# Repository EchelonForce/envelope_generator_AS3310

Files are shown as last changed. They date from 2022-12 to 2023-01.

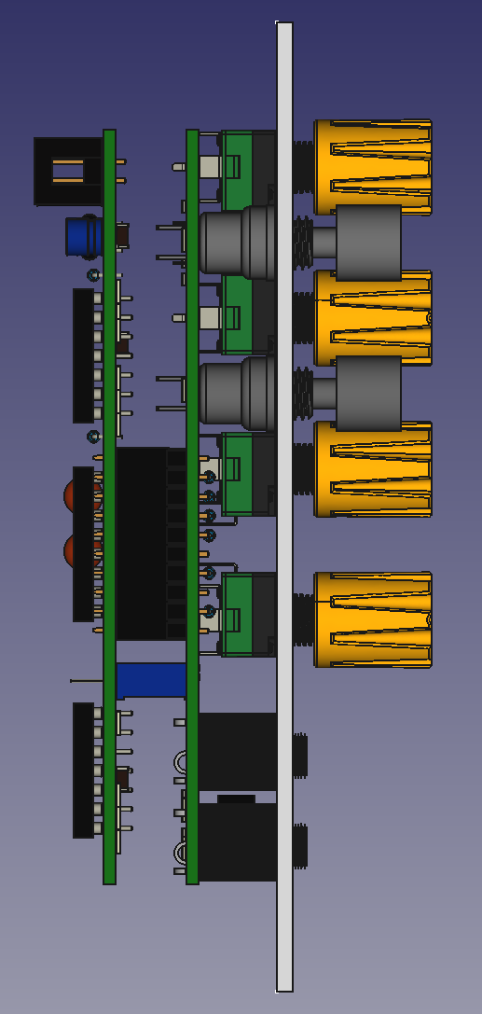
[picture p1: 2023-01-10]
front_panel_v1/render3.png

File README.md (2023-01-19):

# Eurorack Envelope Generator AS3310 

This is a design for a Eurorack Envelope Generator based on the AS3310.

Full write up: https://www.robotdialogs.com/2023/01/eurorack-envelope-generator-adsr-as3310.html

This work is licensed under a Creative Commons Attribution-NonCommercial-ShareAlike 4.0 International License. https://creativecommons.org/licenses/by-nc-sa/4.0/

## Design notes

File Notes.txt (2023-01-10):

Issues on v1:
 - Two header pins flipped (out/release) requires rework.

Changes for v1.1
 - Fix header pins flipped.
 - Add orientation of trim pots to silkscreen.

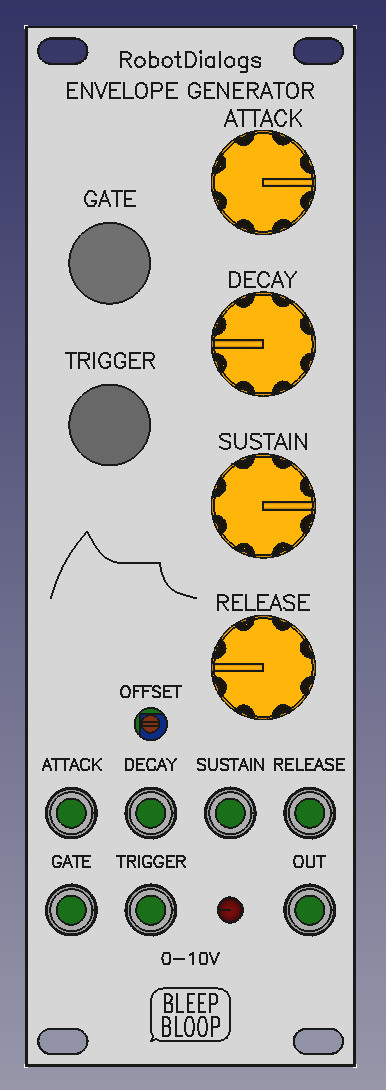
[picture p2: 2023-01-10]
front_panel_v1/render1.png

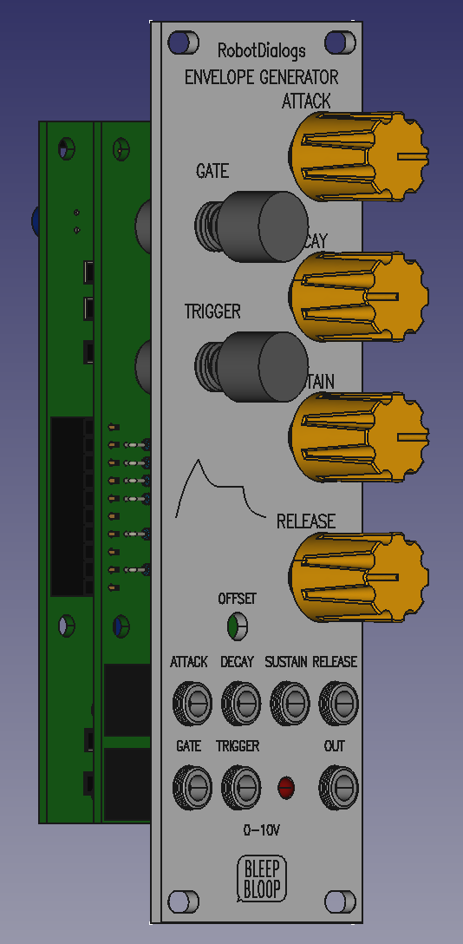
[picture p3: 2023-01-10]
front_panel_v1/render2.png

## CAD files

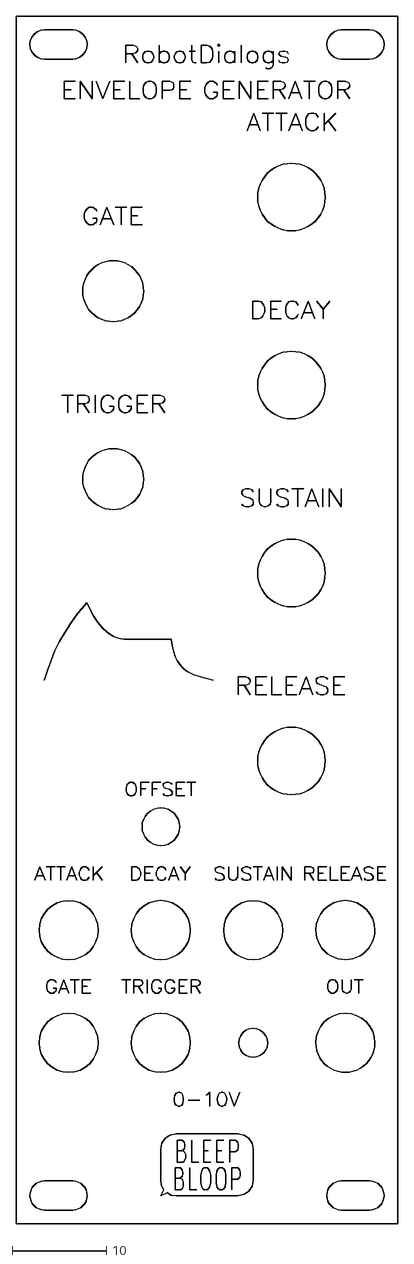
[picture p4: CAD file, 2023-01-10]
front_panel_v1/envelope_v1_front_panel_v1_engraving.dxf
40.5 x 128.4

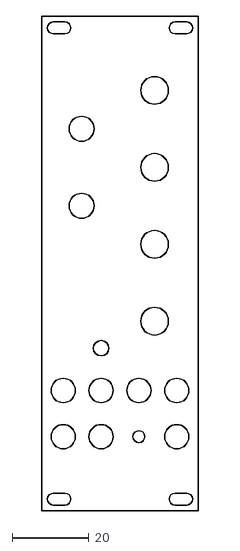
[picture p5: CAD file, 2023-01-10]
front_panel_v1/envelope_v1_front_panel_v1_no_engraving.dxf
40.6 x 128.5

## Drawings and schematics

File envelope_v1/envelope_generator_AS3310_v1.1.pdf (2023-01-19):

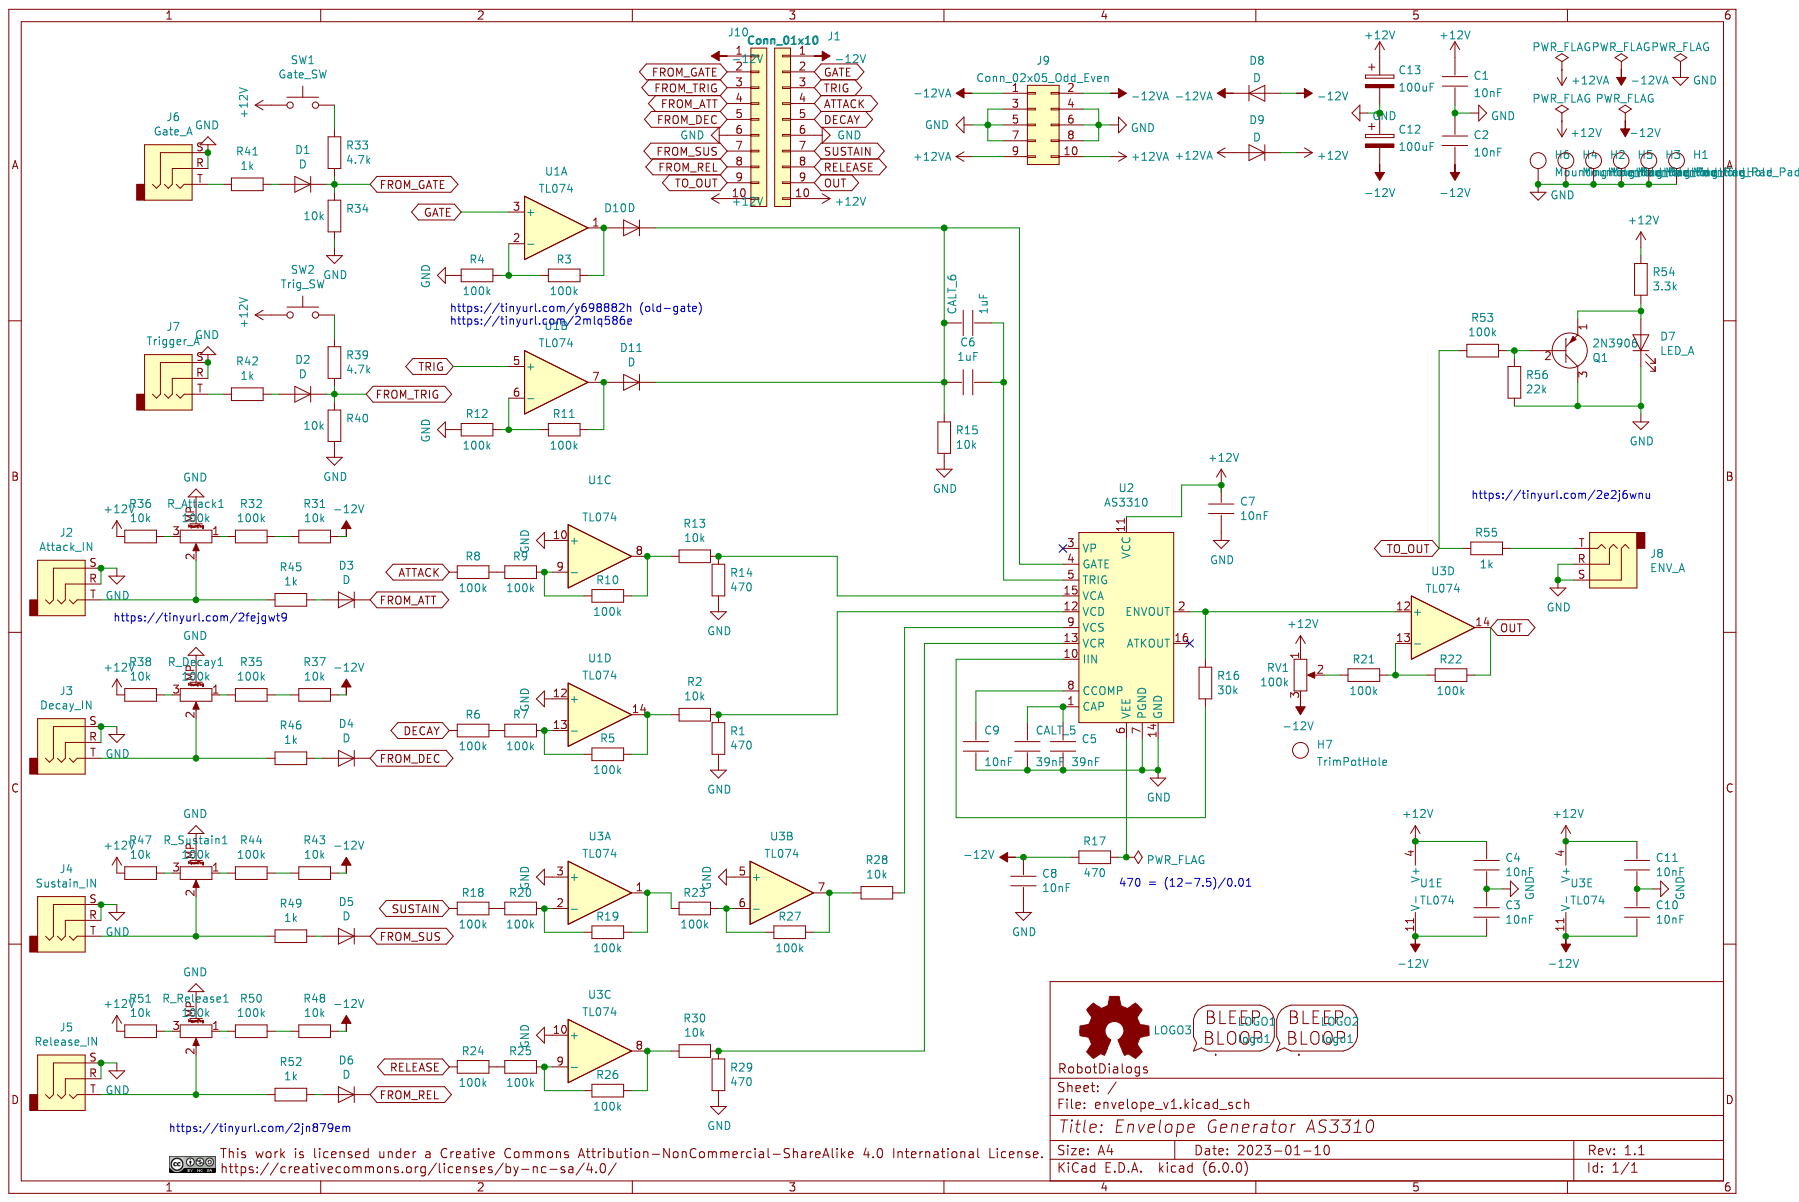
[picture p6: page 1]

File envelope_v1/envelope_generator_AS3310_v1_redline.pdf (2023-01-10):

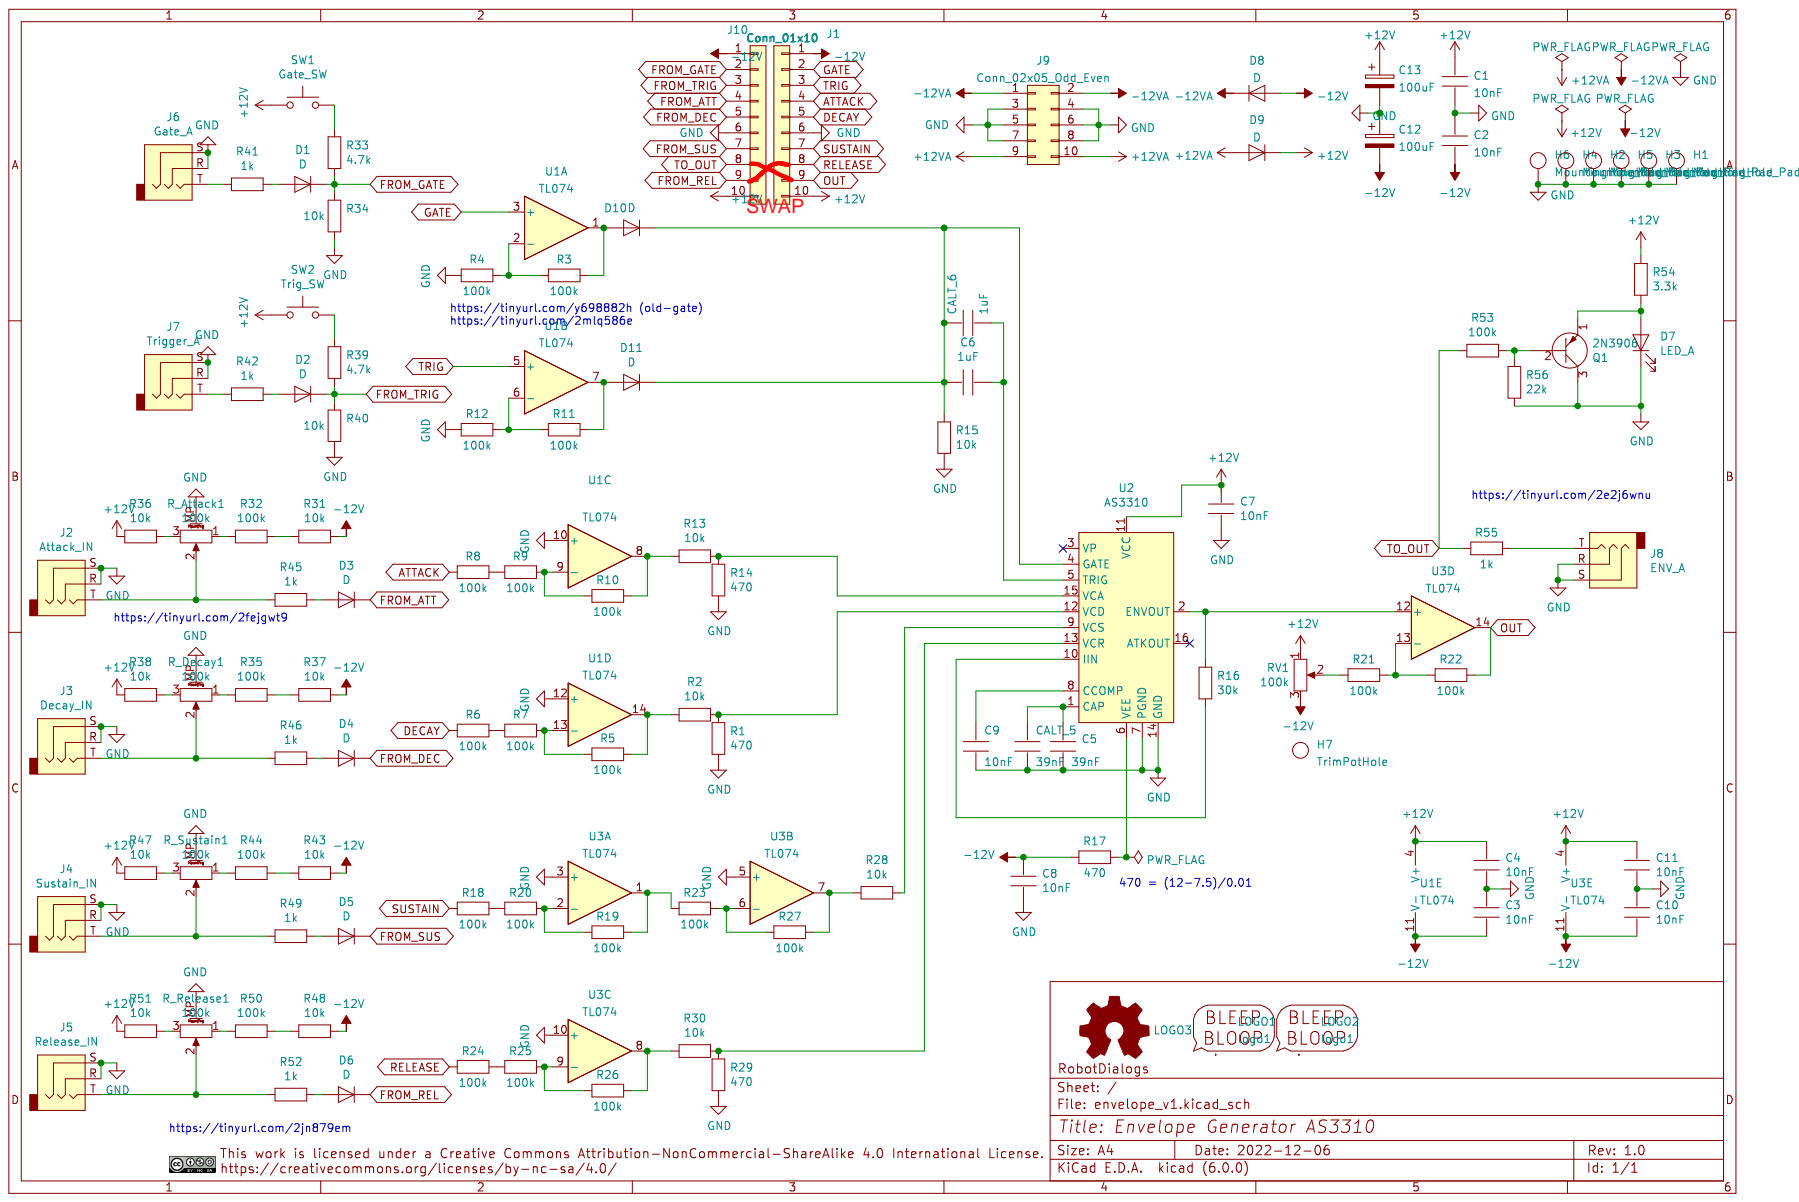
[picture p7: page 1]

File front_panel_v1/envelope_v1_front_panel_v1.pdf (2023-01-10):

1

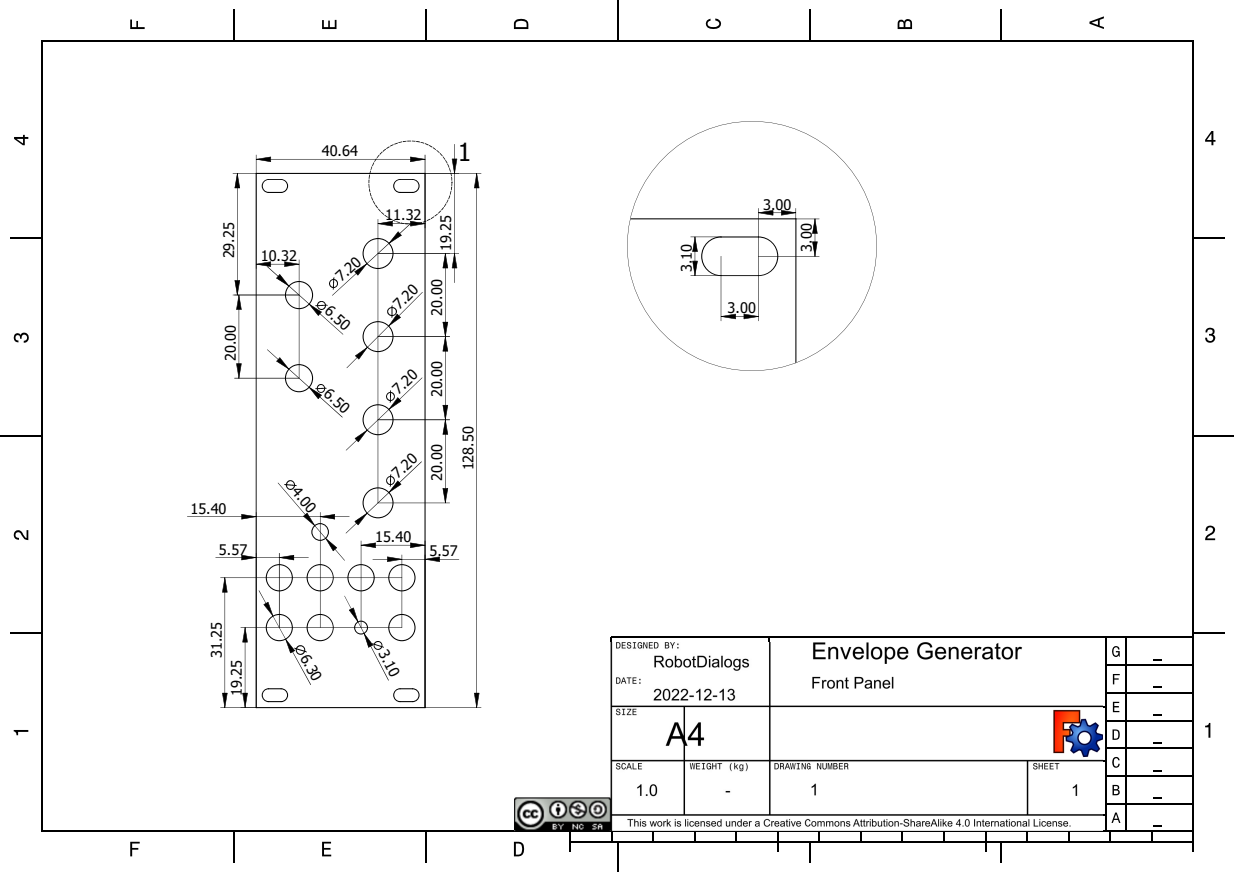
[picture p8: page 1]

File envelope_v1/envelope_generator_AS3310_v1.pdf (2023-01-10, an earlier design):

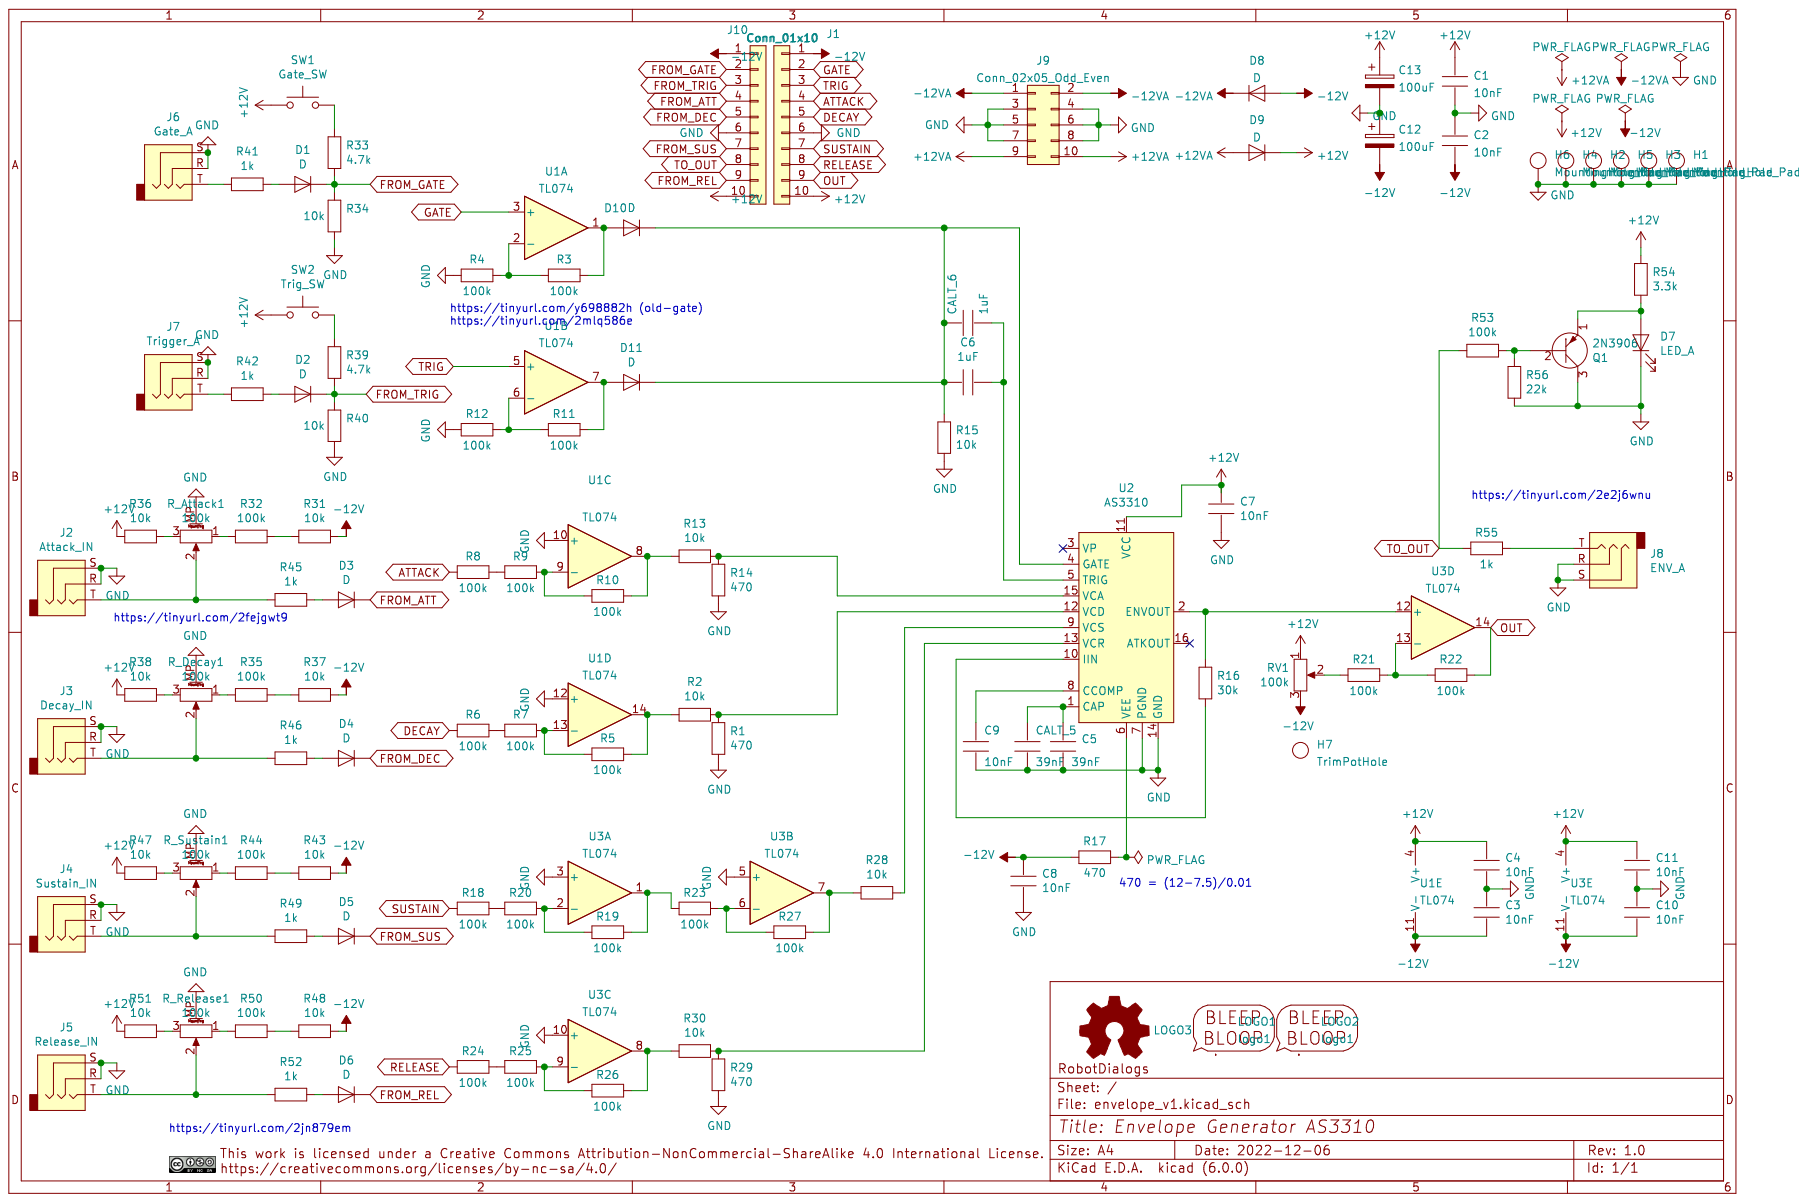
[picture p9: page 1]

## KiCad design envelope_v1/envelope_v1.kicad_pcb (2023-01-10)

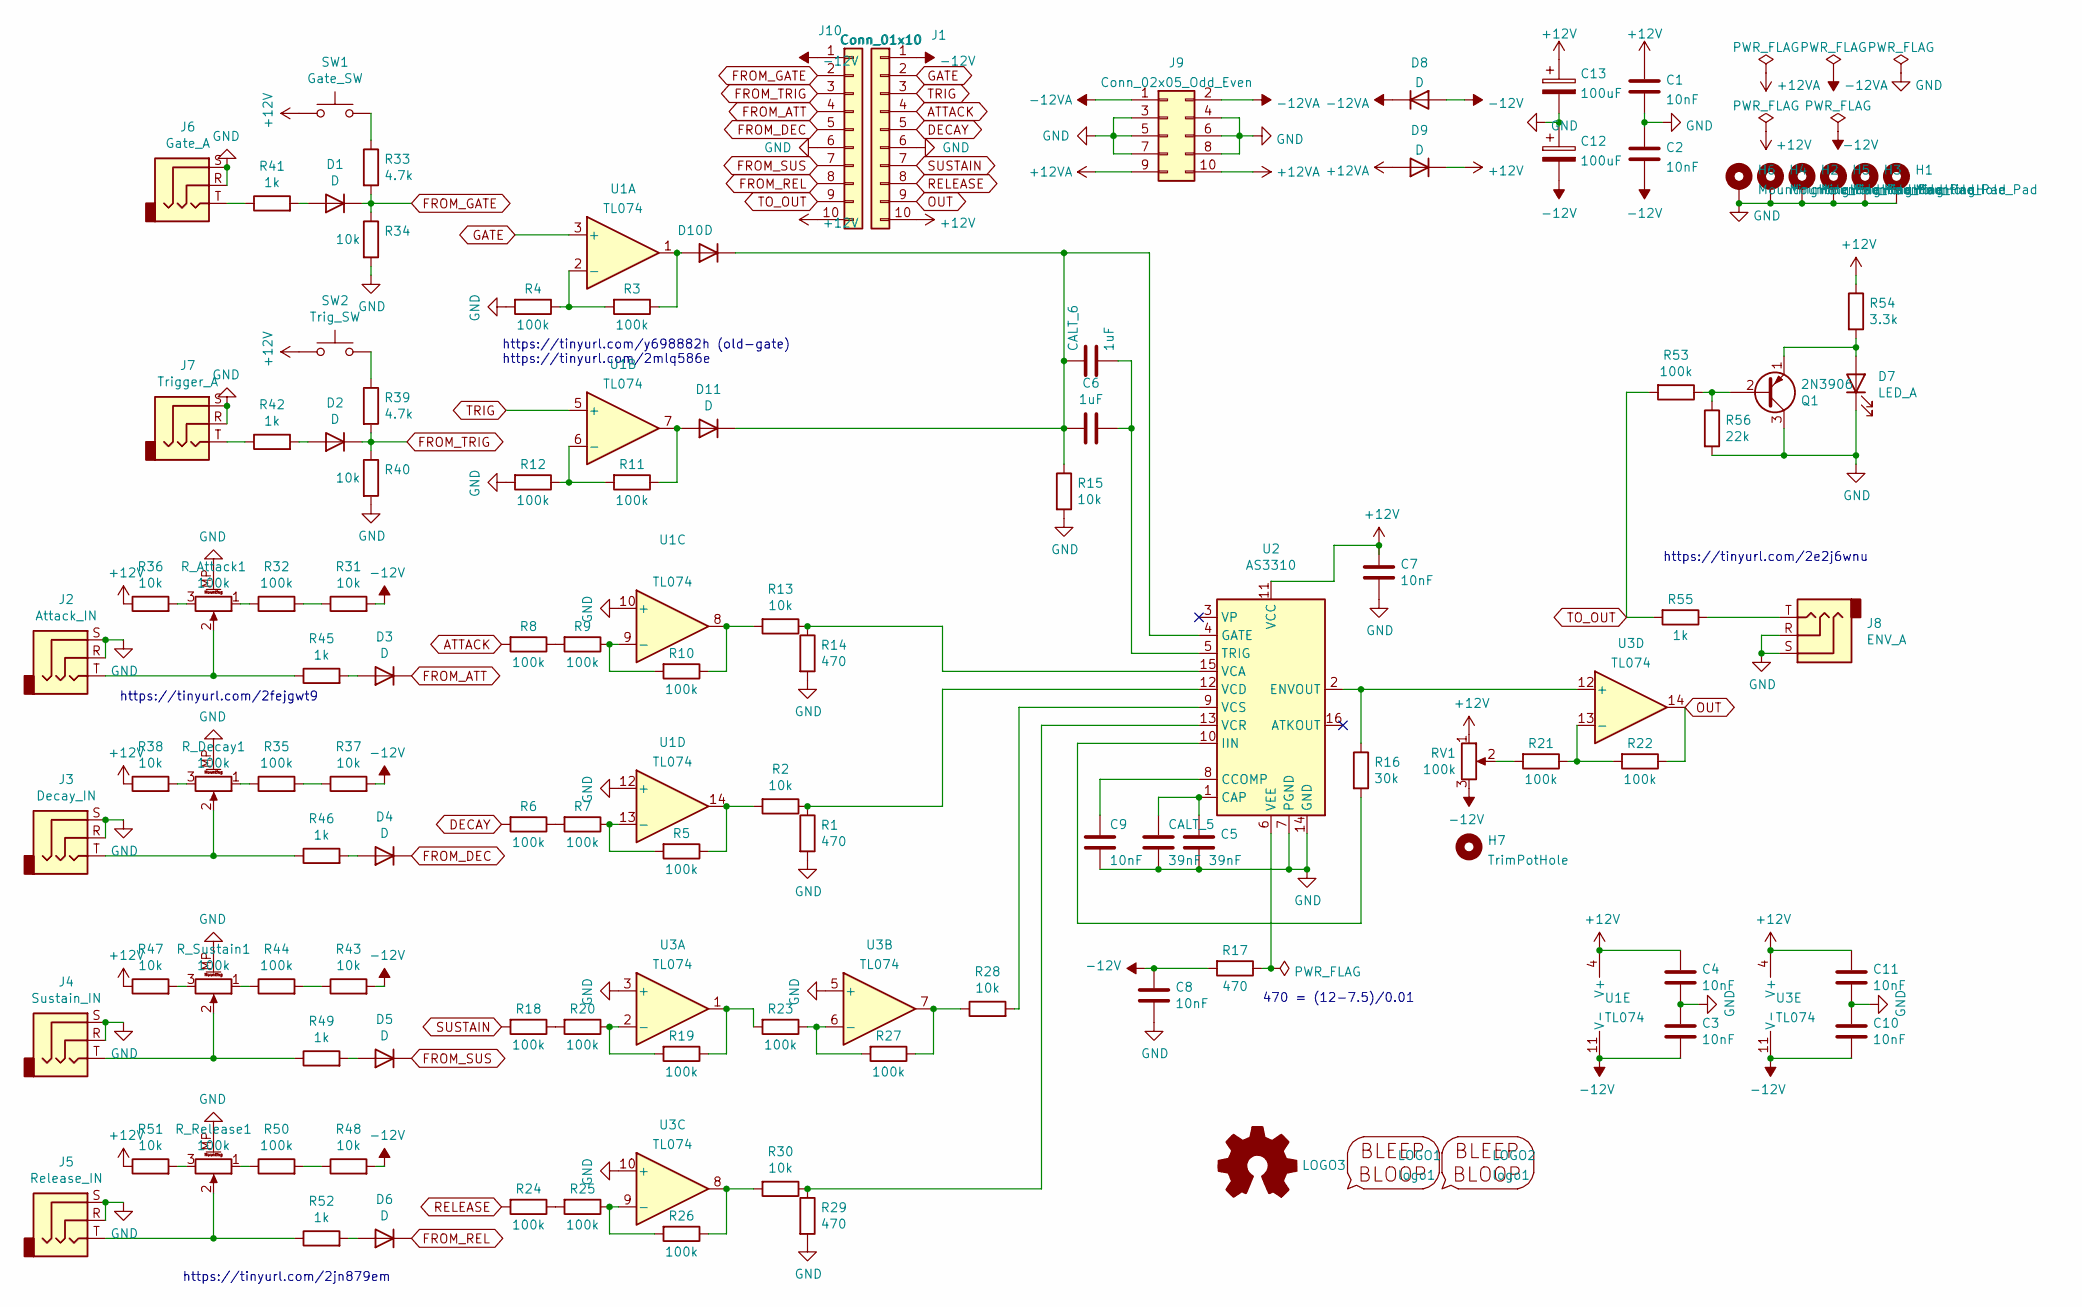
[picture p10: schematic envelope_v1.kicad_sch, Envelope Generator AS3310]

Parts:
C1, C2, C3, C4, C7, C8, C9, C10, C11: 10nF; C_1206_3216Metric_Pad1.33x1.80mm_HandSolder
C5: 39nF; C_1206_3216Metric_Pad1.33x1.80mm_HandSolder
C6: 1uF; C_1206_3216Metric_Pad1.33x1.80mm_HandSolder
C12, C13: 100uF; CP_Radial_D5.0mm_P2.50mm
CALT_5: 39nF; C_Disc_D5.1mm_W3.2mm_P5.00mm
CALT_6: 1uF; C_Disc_D5.1mm_W3.2mm_P5.00mm
D1, D2, D3, D4, D5, D6, D10, D11: D; D_DO-34_SOD68_P7.62mm_Horizontal
D7: LED_A; LED_D3.0mm
D8, D9: D; D_DO-41_SOD81_P10.16mm_Horizontal
H1, H2, H3, H4, H5, H6: MountingHole_Pad; MountingHole_3.2mm_M3_ISO7380_Pad_TopBottom
H7: TrimPotHole; MountingHole_4.3mm_M4_ISO14580
J1: Conn_01x10; PinSocket_1x10_P2.54mm_Vertical
J2: Attack_IN; Jack_3.5mm_MJ-355W_Vertical
J3: Decay_IN; Jack_3.5mm_MJ-355W_Vertical
J4: Sustain_IN; Jack_3.5mm_MJ-355W_Vertical
J5: Release_IN; Jack_3.5mm_MJ-355W_Vertical
J6: Gate_A; Jack_3.5mm_MJ-355W_Vertical
J7: Trigger_A; Jack_3.5mm_MJ-355W_Vertical
J8: ENV_A; Jack_3.5mm_MJ-355W_Vertical
J9: Conn_02x05_Odd_Even; IDC-Header_2x05_P2.54mm_Vertical
J10: Conn_01x10; PinHeader_1x10_P2.54mm_Vertical
LOGO1: logo1; Logo1
LOGO2: logo1; Logo2
LOGO3: Logo_Open_Hardware_Small; OSHW-Symbol_6.7x6mm_SilkScreen
Q1: 2N3906; TO-92_Inline_Wide
R1, R14, R17, R29: 470; R_1206_3216Metric_Pad1.30x1.75mm_HandSolder
R2, R13, R15, R28, R30, R31, R34, R36, R37, R38, R40, R43, R47, R48, R51: 10k; R_1206_3216Metric_Pad1.30x1.75mm_HandSolder
R3, R4, R5, R6, R7, R8, R9, R10, R11, R12, R18, R19, R20, R21, R22, R23, R24, R25, R26, R27, R32, R35, R44, R50, R53: 100k; R_1206_3216Metric_Pad1.30x1.75mm_HandSolder
R16: 30k; R_1206_3216Metric_Pad1.30x1.75mm_HandSolder
R33, R39: 4.7k; R_1206_3216Metric_Pad1.30x1.75mm_HandSolder
R41, R42, R45, R46, R49, R52, R55: 1k; R_1206_3216Metric_Pad1.30x1.75mm_HandSolder
R54: 3.3k; R_1206_3216Metric_Pad1.30x1.75mm_HandSolder
R56: 22k; R_1206_3216Metric_Pad1.30x1.75mm_HandSolder
RV1: 100k; Potentiometer_Bourns_3296W_Vertical
R_Attack1: 100k; Potentiometer_Alpha_RD901F-40-00D_Single_Vertical_w_3d
R_Decay1: 100k; Potentiometer_Alpha_RD901F-40-00D_Single_Vertical_w_3d
R_Release1: 100k; Potentiometer_Alpha_RD901F-40-00D_Single_Vertical_w_3d
R_Sustain1: 100k; Potentiometer_Alpha_RD901F-40-00D_Single_Vertical_w_3d
SW1: Gate_SW; SW_PS1024ALRED
SW2: Trig_SW; SW_PS1024ALRED
U1, U3: TL074; DIP-14_W7.62mm_Socket_LongPads
U2: AS3310; DIP-16_W7.62mm_Socket_LongPads

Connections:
+12V: C1.1, C4.2, C7.2, C11.2, C13.1, D9.1 (K), J1.10, J10.10, R36.1, R38.1, R47.1, R51.1, R54.1, RV1.1, SW1.1, SW2.1, U1.4 (V+), U2.11 (VCC), U3.4 (V+)
+12VA: D9.2 (A), J9.9, J9.10
-12V: C2.2, C3.1, C8.2, C10.1, C12.2, D8.2 (A), J1.1, J10.1, R17.2, R31.2, R37.2, R43.2, R48.2, RV1.3, U1.11 (V-), U3.11 (V-)
-12VA: D8.1 (K), J9.1, J9.2
ATTACK: J1.4, R8.2
DECAY: J1.5, R6.2
FROM_ATT: D3.1 (K), J10.4
FROM_DEC: D4.1 (K), J10.5
FROM_GATE: D1.1 (K), J10.2, R33.2, R34.1
FROM_REL: D6.1 (K), J10.8
FROM_SUS: D5.1 (K), J10.7
FROM_TRIG: D2.1 (K), J10.3, R39.2, R40.1
GATE: J1.2, U1.3 (+)
GND: C1.2, C2.1, C3.2, C4.1, C5.2, C7.1, C8.1, C9.2, C10.2, C11.1, C12.1, C13.2, CALT_5.2, D7.1 (K), H1.1, H2.1, H3.1, H4.1, H5.1, H6.1, J1.6, J2.R, J2.S, J3.R, J3.S, J4.R, J4.S, J5.R, J5.S, J6.R, J6.S, J7.R, J7.S, J8.R, J8.S, J9.3, J9.4, J9.5, J9.6, J9.7, J9.8, J10.6, Q1.3 (C), R1.2, R4.2, R12.2, R14.2, R15.2, R29.2, R34.2, R40.2, R56.2, R_Attack1.MP (MountPin), R_Decay1.MP (MountPin), R_Release1.MP (MountPin), R_Sustain1.MP (MountPin), U1.10 (+), U1.12 (+), U2.7 (PGND), U2.14 (GND), U3.3 (+), U3.5 (+), U3.10 (+)
unnamed: C5.1, CALT_5.1, U2.1 (CAP)
unnamed: C6.1, CALT_6.1, D10.1 (K), D11.1 (K), R15.1, U2.4 (GATE)
unnamed: C6.2, CALT_6.2, U2.5 (TRIG)
unnamed: C9.1, U2.8 (CCOMP)
unnamed: D1.2 (A), R41.2
unnamed: D2.2 (A), R42.2
unnamed: D3.2 (A), R45.2
unnamed: D4.2 (A), R46.2
unnamed: D5.2 (A), R49.2
unnamed: D6.2 (A), R52.2
unnamed: D7.2 (A), Q1.1 (E), R54.2
unnamed: D10.2 (A), R3.1, U1.1
unnamed: D11.2 (A), R11.1, U1.7
unnamed: J2.T, R45.1, R_Attack1.2
unnamed: J3.T, R46.1, R_Decay1.2
unnamed: J4.T, R49.1, R_Sustain1.2
unnamed: J5.T, R52.1, R_Release1.2
unnamed: J6.T, R41.1
unnamed: J7.T, R42.1
unnamed: J8.T, R55.1
unnamed: Q1.2 (B), R53.1, R56.1
unnamed: R1.1, R2.1, U2.12 (VCD)
unnamed: R2.2, R5.1, U1.14
unnamed: R3.2, R4.1, U1.2 (-)
unnamed: R5.2, R7.1, U1.13 (-)
unnamed: R6.1, R7.2
unnamed: R8.1, R9.2
unnamed: R10.1, R13.2, U1.8
unnamed: R9.1, R10.2, U1.9 (-)
unnamed: R11.2, R12.1, U1.6 (-)
unnamed: R13.1, R14.1, U2.15 (VCA)
unnamed: R16.1, U2.2 (ENVOUT), U3.12 (+)
unnamed: R16.2, U2.10 (IIN)
unnamed: R17.1, U2.6 (VEE)
unnamed: R18.1, R20.2
unnamed: R19.1, R23.2, U3.1
unnamed: R19.2, R20.1, U3.2 (-)
unnamed: R21.1, R22.2, U3.13 (-)
unnamed: R21.2, RV1.2
unnamed: R23.1, R27.2, U3.6 (-)
unnamed: R24.1, R25.2
unnamed: R25.1, R26.2, U3.9 (-)
unnamed: R26.1, R30.2, U3.8
unnamed: R27.1, R28.1, U3.7
unnamed: R28.2, U2.9 (VCS)
unnamed: R29.1, R30.1, U2.13 (VCR)
unnamed: R31.1, R32.2
unnamed: R32.1, R_Attack1.1
unnamed: R33.1, SW1.2
unnamed: R35.1, R_Decay1.1
unnamed: R35.2, R37.1
unnamed: R36.2, R_Attack1.3
unnamed: R38.2, R_Decay1.3
unnamed: R39.1, SW2.2
unnamed: R43.1, R44.2
unnamed: R44.1, R_Sustain1.1
unnamed: R47.2, R_Sustain1.3
unnamed: R48.1, R50.2
unnamed: R50.1, R_Release1.1
unnamed: R51.2, R_Release1.3
OUT: J1.9, R22.1, U3.14
RELEASE: J1.8, R24.2
SUSTAIN: J1.7, R18.2
TO_OUT: J10.9, R53.2, R55.2
TRIG: J1.3, U1.5 (+)

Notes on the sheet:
https://tinyurl.com/y698882h (old-gate) https://tinyurl.com/2mlq586e
470 = (12-7.5)/0.01
https://tinyurl.com/2fejgwt9
https://tinyurl.com/2jn879em
https://tinyurl.com/2e2j6wnu

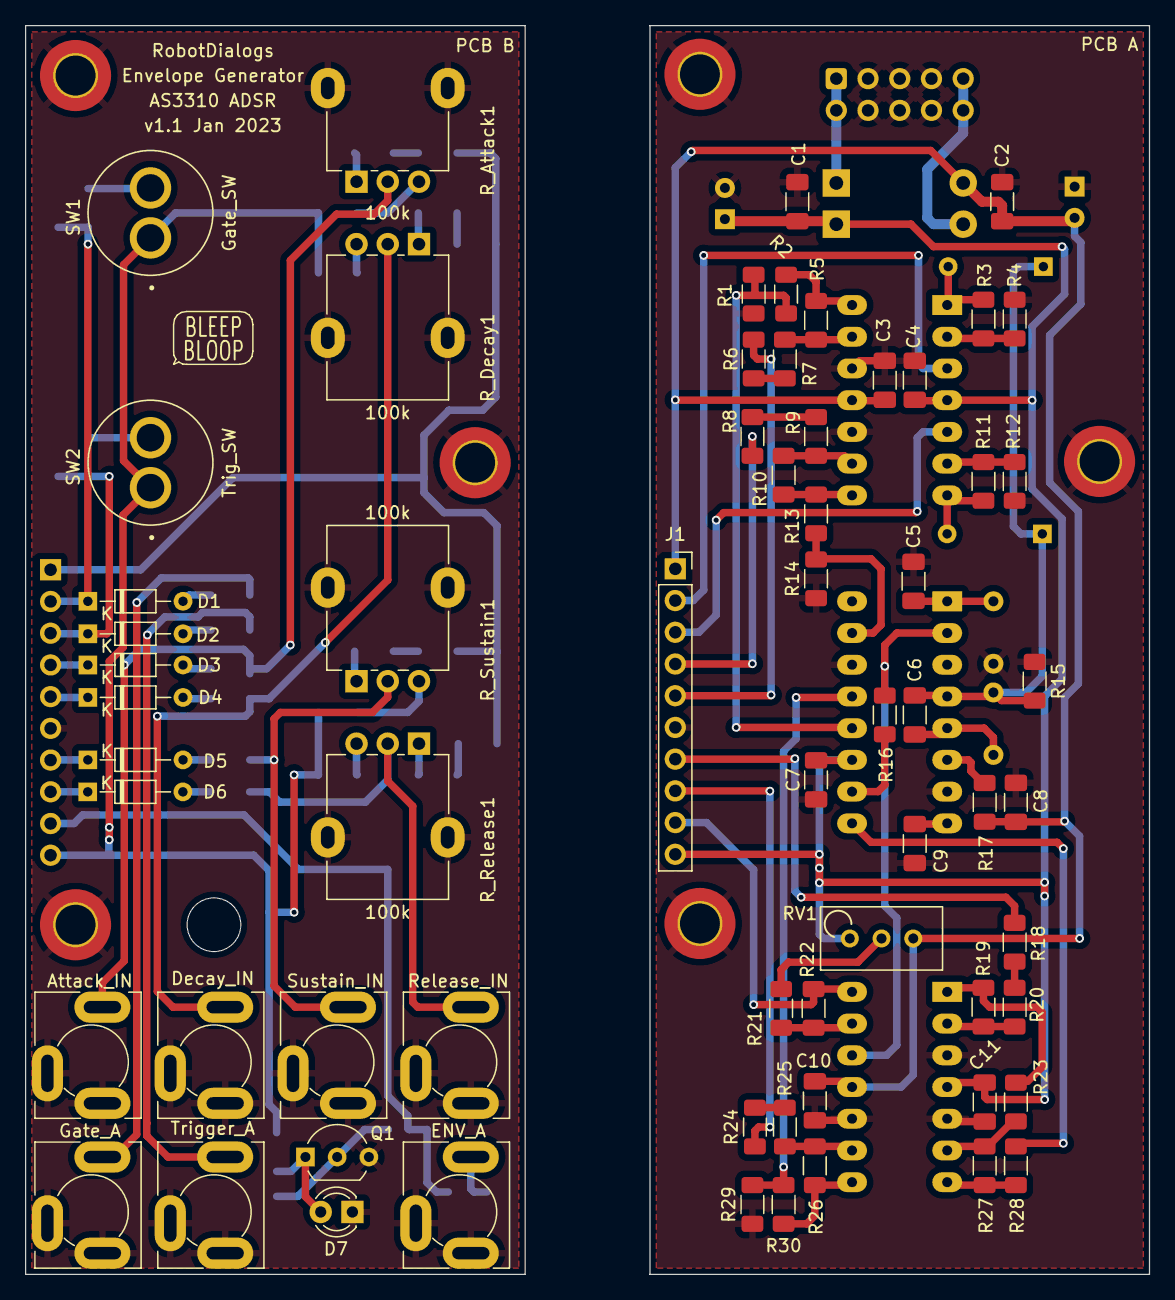
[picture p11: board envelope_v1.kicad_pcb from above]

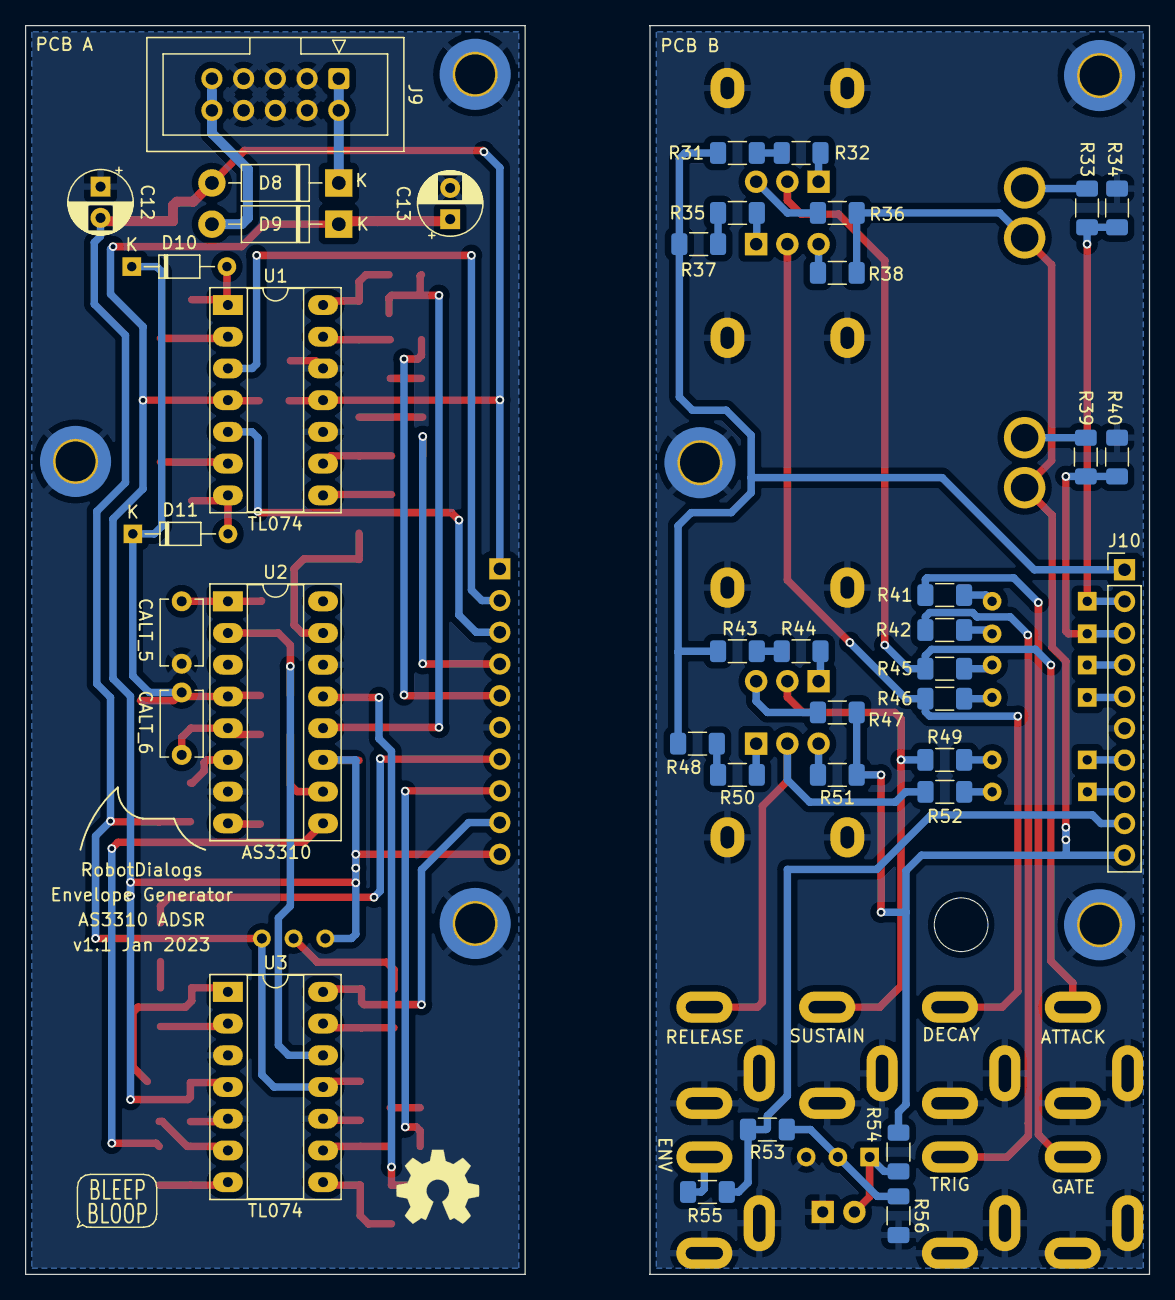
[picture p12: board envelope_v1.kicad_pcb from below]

Board: 2 copper layers, 90.0 x 100.0 mm, 113 parts (40 on the bottom side), 79 nets.

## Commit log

2022-12-07 Schematic and PCB draft
    [envelope_v1.kicad_pcb, envelope_v1.kicad_sch]
2022-12-07 Geographic re-annotate
    [envelope_v1.kicad_pcb, envelope_v1.kicad_sch]
2022-12-07 Cleanup and labels
    [envelope_v1.kicad_pcb, envelope_v1.kicad_sch]
2022-12-11 Panelized v1
    [envelope_v1_pcb_a.kicad_pcb, envelope_v1_pcb_b.kicad_pcb]
2023-01-10 Front Panel v1 docs
    [envelope_v1_front_panel_v1_engraving.dxf, envelope_v1_front_panel_v1_no_engraving.dxf]
2023-01-10 v1.1 fixes
    [envelope_v1.kicad_pcb, envelope_v1.kicad_sch]
2023-01-10 panelized v1.1
    [envelope_v1_1_pcb_a.kicad_pcb, envelope_v1_1_pcb_b.kicad_pcb]
2023-01-19 Add v1.1 schematic pdf
